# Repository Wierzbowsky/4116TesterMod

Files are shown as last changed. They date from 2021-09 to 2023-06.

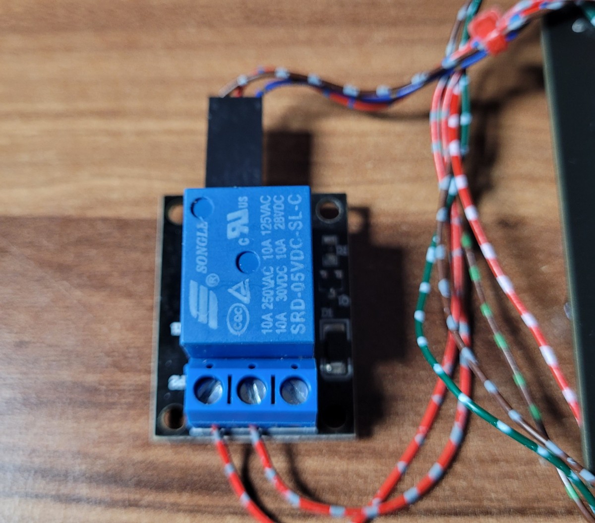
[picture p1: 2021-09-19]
Pics/relay.jpg

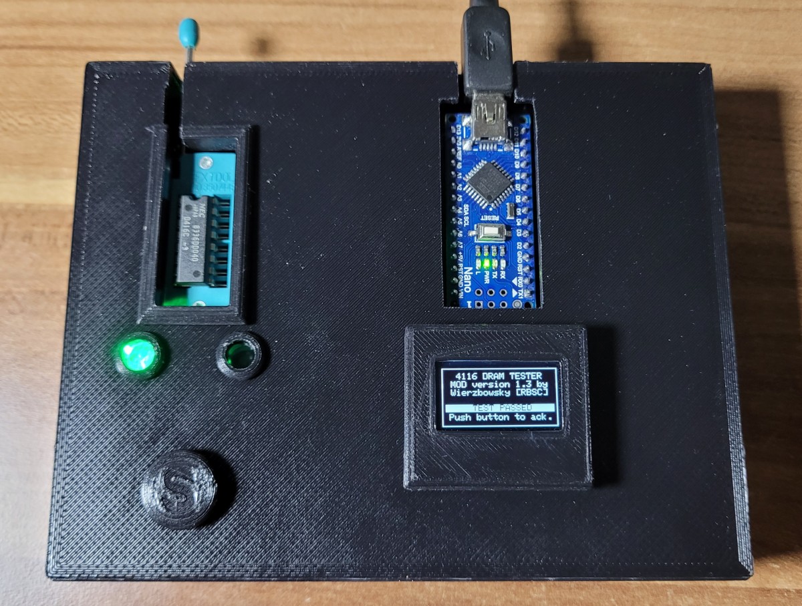
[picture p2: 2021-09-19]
Pics/case2.jpg

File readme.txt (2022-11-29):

--------------------------------------------------------------------------------
4116 DRAM Tester v3.0
Firmware fix by Uffe Lund-Hansen, 2017-2020
Mods by Alex Wierzbowsky [RBSC], 2021-2022
--------------------------------------------------------------------------------

WARNING!
If you applied the power mod to the tester, do not use the 9v power socket!
Power the tester only with the USB cable connected to Ardino Nano's Mini/MicroUSB connector.

IMPORTANT!
It's recommended to use a computer's USB3 port to power the tester because USB3 provides enough current
for the device to work properly. You can also power the tester with any 5v 500mA rated power supply that
is connected to the Mini/MicroUSB connector (for example phone charger).

ABOUT
-----

The original project was created in November 2017. The code was officially released in March 2020. Most of the
code and design was coming from http://forum.defence-force.org/viewtopic.php?p=15035&sid=17bf402b9c2fd97c8779668b8dde2044
by forum's member "iss" and was modified to work with 4116 DRAM by Uffe Lund-Hansen, Frostbox Labs.

The board for the project was modded from the original design by Muttley Black. However, the board was not safe
to use because there was always power on the chip's socket. Inserting a DRAM chip with the enabled +12v, -5v
and +5v is rather dangerous and in case of a wrongly inserted chip, damage may occur to the chip and the tester
itself.

Also, the firmware was designed to run only once, then the Arduino had to be reset by the Start button or by
the on-board reset button. The original firmware also had some minimal serial interface reporting capabilities.

Taking into account the above mentioned drawbacks, it was decided to mod the tester's hardware and firmware
in order to make it safer and more usable. Three mods were created for this project:

1. Button mod: v1.1

   This is simple. The button needs to be disconnected from RST pin and connected to A6 pin of Arduino Nano.
   The firmware was modified to use the button not to reset the Arduino, but to start a test and then confirm
   the test result. Some led blinking was added to indicate in which mode the tester is at any moment. If
   both LEDs are blinking, the tester awaits a chip to be inserted and the button to be pressed for the test
   to start. If green or red LED is lit, this indicates a successful or a failed test. The serial interface
   messages were improved to report the test results, tester's version and when the tester needs a user's
   interaction.

2. Power mod: v1.2

   This mod requires the Button mod to be installed!

   The power mod was created to disable the power on the chip's socket and to only enable it during testing. This
   makes it safe to insert a DRAM chip and also quickly cuts off the power in case a chip is shorted or inserted
   in a wrong way. The simple relay module for Arduino was used to enable or disable +5v power to the socket and
   +12v and -5v converters. The 5v track needs to be cut in 2 places, one wire needs to be added from the cut
   off +5v track to pin 9 of the socket. And the relay needs to be connected to both sides of the cut track.

   The relay is controlled by the signal that has to be connected to D12 pin of Arduino Nano. The relay's control
   circuit needs its own power and ground wires, the +5v has to be taken from the always powered part of the
   circuit. See the pictures in the "Pic" folder for the necessary modifications.

3. OLED screen mod: v1.3

   This mod requires at least the Button mod to be installed!

   To make the tester more informative an OLED screen was added into the project. As Arduino Nano has SCL and SDA
   signals available on A4 and A5 pins and those pins were used by the original tester's designer for the chip's
   socket, before the screen's installation those connections need to be rewired. A4 needs to be rewired to D10
   and A5 needs to be rewired to D11 pins of Arduino Nano. The tracks from A4 and A5 leading to resistors need to
   be cut. Then the screen's SCL and SDA pins need to be connected to Arduino's SCL and SDA pins. See Arduino's
   pinout for reference. Don't forget to connect VCC pin of the screen to Arduino's 3.3v pin and the GND pin of
   the screen to one of GND pins of the Arduino or to any other solder point on the ground plane. See the
   pictures in the "Pic" folder for the necessary modifications.

   The mod is designed to work with the 128x64 SSD1306 OLED screen. Before compiling the firmware please add the
   required Adafruit libaray for SSD1306 screen into your Arduino IDE environment.

   Because of the large size of the firmware after adding the support for the OLED screen, the serial interface
   messages were commented out to save space in the firmware.

When applying the mods, don't forget to upload the corresponding firmware version into Arduino Nano. See the
"Firmware" folder for the available firmwares. Some Arduinos may require selecting "older Bootloader" option
in the IDE to be flashed.

And finally, 3D models of the case were created for the project. There's a wide case that can hold the relay
board and a narrow case for the tester's board by Muttley Black. Both cases can be used for installing the
OLED screen's frame. If you only want the button and screen mods, you can use the narrow case. Please keep
in mind that if you are installing the boards into these cases, you will need to make the socket's lever a bit
longer by attaching a thin plastic or metal tube to it. The current case's design is not ideal for inserting
DRAM chips, so it's recommended to use tweezers if you have trouble inserting or removing a chip.

The Gerber files for that board are located in the "Gerber" folder. The 3D models of the case as well as frames
for the screen are also available in the "Case" folder. The "Original" folder contains the narrow case, the
"Modded" folder contains the wide case.

The videos of the tester's mods can be found on Wierzbowsky's YouTube channel:
https://www.youtube.com/channel/UCefKNRX9MJG4uGqiBBtaJVA/videos

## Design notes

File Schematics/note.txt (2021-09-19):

This schematics doesn't include the modifications added by Muttley Black. The modifications included adding
twelve 150 Ohm current limiting resistors between the Arduino Nano and the chip's socket.

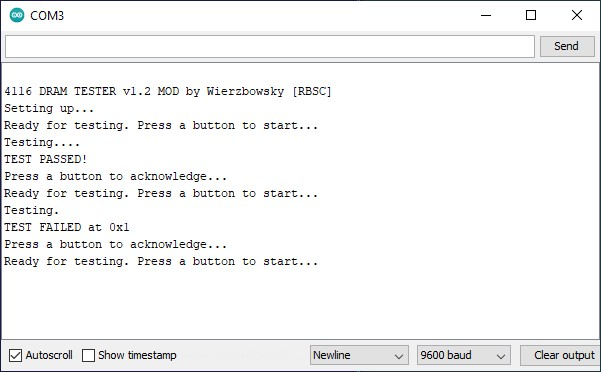
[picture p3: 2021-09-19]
Pics/serial_io.png

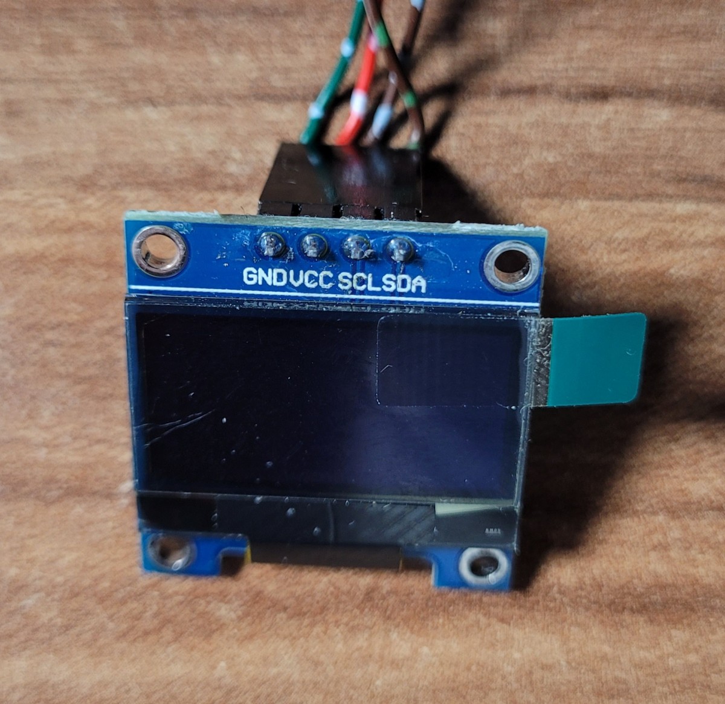
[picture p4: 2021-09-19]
Pics/screen.jpg

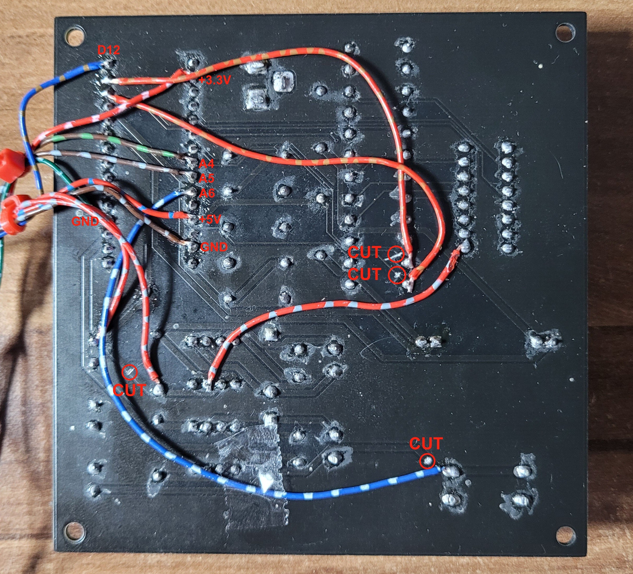
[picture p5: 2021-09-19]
Pics/board_back.jpg

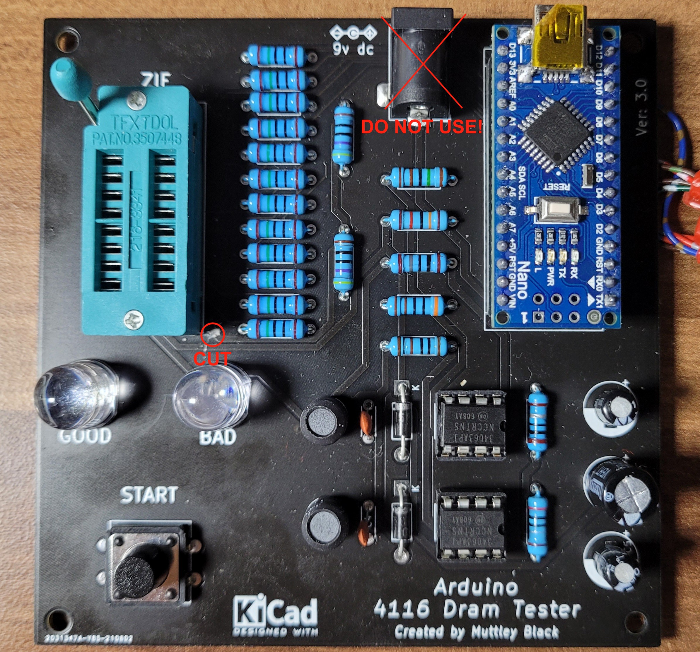
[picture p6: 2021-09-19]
Pics/board_front.jpg

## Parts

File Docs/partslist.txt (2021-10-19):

1  A1 - Arduino Nano v3.x : Module:Arduino Nano 
2  C1 - 100uF 16V : Capacitor THT:CP Radial D8.0mm P3.80mm 
3  C2 - 470pF : Capacitor THT:C_Disc_D4.3mm W1.9mm P5.00mm 
4  C3 - 470uF 16V : Capacitor THT:CP Radial D8.0mm P3.80mm 
5  C4 - 330pF : Capacitor THT:C_Disc_D4.3mm W1.9mm P5.00mm 
6  C5 - 100uF 16V : Capacitor THT:CP Radial D8.0mm P3.80mm 
7  D1 - Green : LED THT:LED D5.0mm 
8  D2 - Red : LED THT:LED D5.0mm 
9  D3 - 1N5819 : Diode_THT:D_DO-41_SOD81_P10.16mm Horizontal 
10 D4 - 1N5819 : Diode_THT:D_DO-41_SOD81_P10.16mm Horizontal 
11 J1 - ZIF socket 16 pin : Socket:DIP_Socket-16 W4.3 W5.08 W7.62 W10.16 W10.9_3M 216-3340-00-0602J 
12 J2 - 9v dc : Connector_BarrelJack:BarrelJack Horizontal 
13 L1 - 2mH : Inductor THT:L Radial D6.0mm P4.00mm 
14 L2 - 2mH : Inductor THT:L Radial D6.0mm P4.00mm 
15 R1 - 470 Ohm : Resistor THT:R Axial_DINO207_L6.3mm D2.5mm P10.16mm Horizontal 
16 R2 - 470 Ohm : Resistor THT:R Axial_DINO207_L6.3mm D2.5mm P10.16mm Horizontal 
17 R3 - 1 Ohm : Resistor THT:R Axial_DINO207_L6.3mm D2.5mm P10.16mm Horizontal 
18 R4 - 1.5 kOhm : Resistor THT:R Axial_DINO207_L6.3mm D2.5mm P10.16mm Horizontal 
19 R5 - 13 kOhm : Resistor THT:R Axial_DINO207_L6.3mm D2.5mm P10.16mm Horizontal 
20 R6 - 180 Ohm : Resistor THT:R Axial_DINO207_L6.3mm D2.5mm P10.16mm Horizontal 
21 R7 - 2 Ohm  : Resistor THT:R Axial_DINO207_L6.3mm D2.5mm P10.16mm Horizontal 
22 R8 - 3 kOhm : Resistor THT:R Axial_DINO207_L6.3mm D2.5mm P10.16mm Horizontal 
23 R9 - l kOhm : Resistor THT:R Axial_DINO207_L6.3mm D2.5mm P10.16mm Horizontal 
24 R10 - 150 Ohm : Resistor THT:R Axial_DINO207_L6.3mm D2.5mm P10.16mm Horizontal 
25 R11 - 150 Ohm : Resistor THT:R Axial_DINO207_L6.3mm D2.5mm P10.16mm Horizontal 
26 R12 - 150 Ohm : Resistor THT:R Axial_DINO207_L6.3mm D2.5mm P10.16mm Horizontal 
27 R13 - 150 Ohm : Resistor THT:R Axial_DINO207_L6.3mm D2.5mm P10.16mm Horizontal 
28 R14 - 150 Ohm : Resistor THT:R Axial_DINO207_L6.3mm D2.5mm P10.16mm Horizontal 
29 R15 - 150 Ohm : Resistor THT:R Axial_DINO207_L6.3mm D2.5mm P10.16mm Horizontal 
30 R16 - 150 Ohm : Resistor THT:R Axial_DINO207_L6.3mm D2.5mm P10.16mm Horizontal 
31 R17 - 150 Ohm : Resistor THT:R Axial_DINO207_L6.3mm D2.5mm P10.16mm Horizontal 
32 R18 - 150 Ohm : Resistor THT:R Axial_DINO207_L6.3mm D2.5mm P10.16mm Horizontal 
33 R19 - 150 Ohm : Resistor THT:R Axial_DINO207_L6.3mm D2.5mm P10.16mm Horizontal 
34 R20 - 150 Ohm : Resistor THT:R Axial_DINO207_L6.3mm D2.5mm P10.16mm Horizontal 
35 R21 - 150 Ohm : Resistor THT:R Axial_DINO207_L6.3mm D2.5mm P10.16mm Horizontal 
36 SW1 - SW_Push : Button_Switch THT:SW_PUSH-12mm 
37 U1 - MC34063AP : Package_DIP:DIP-8 W7.62mm 
38 U2 - MC34063AP : Package_DIP:DIP-8 W7.62mm

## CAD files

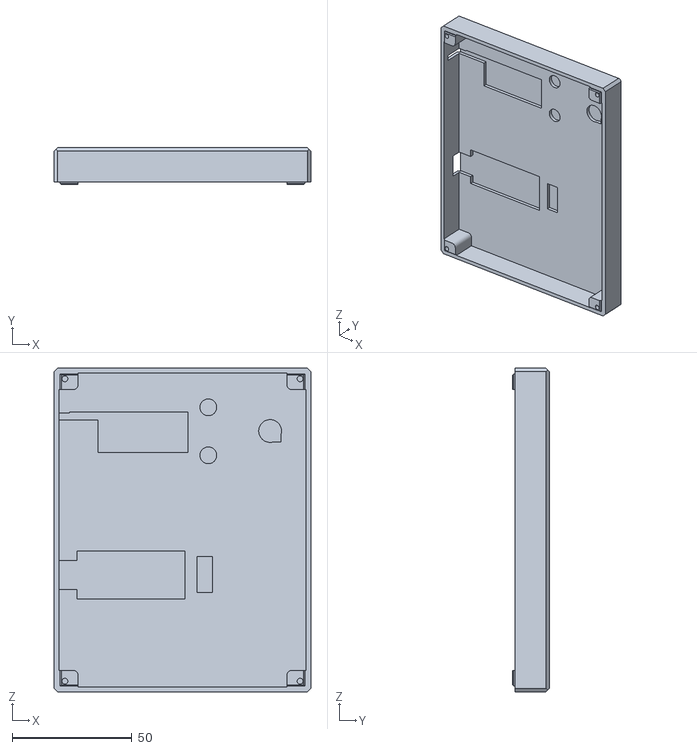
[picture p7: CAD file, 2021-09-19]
Case/Modded/Top_NoHoles.stl
107.0 x 15.5 x 135.0

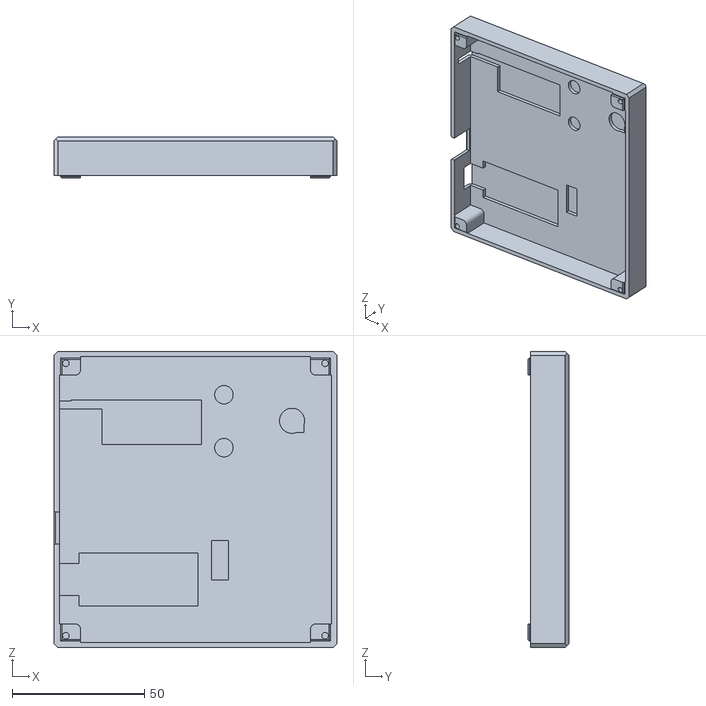
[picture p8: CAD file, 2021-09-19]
Case/Original/Top_NoHoles.stl
107.0 x 15.5 x 112.0

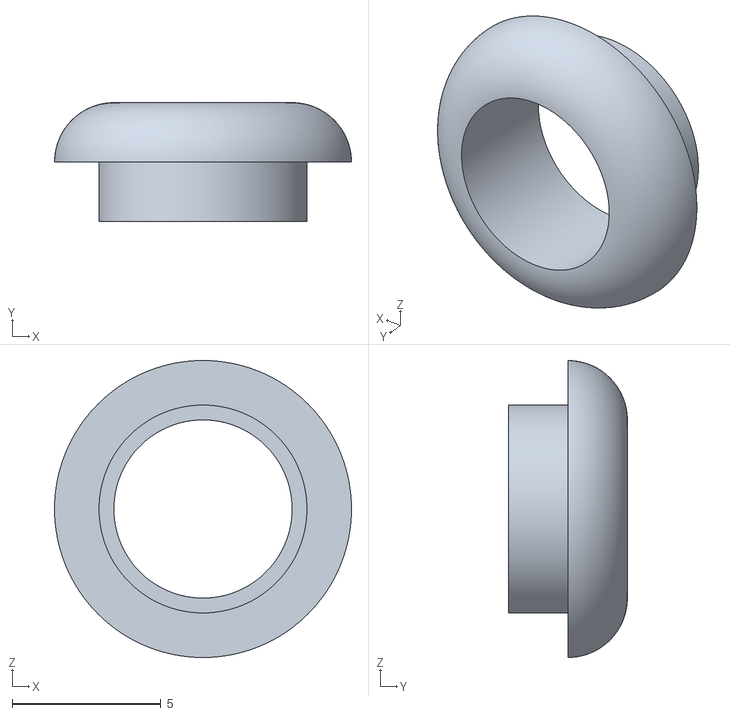
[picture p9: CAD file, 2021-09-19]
Case/Modded/LEDCap.stl
10.0 x 4.00 x 10.0

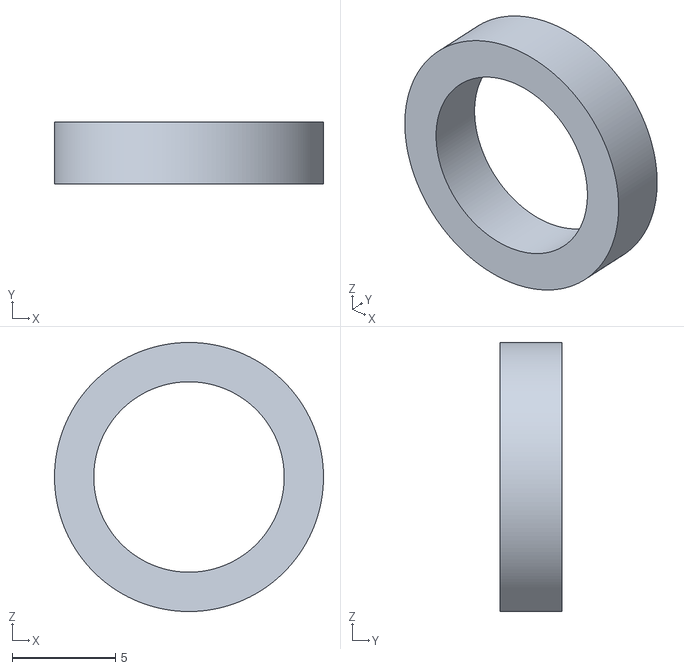
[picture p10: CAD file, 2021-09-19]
Case/Original/ButtoncapLock.stl
13.0 x 3.00 x 13.0

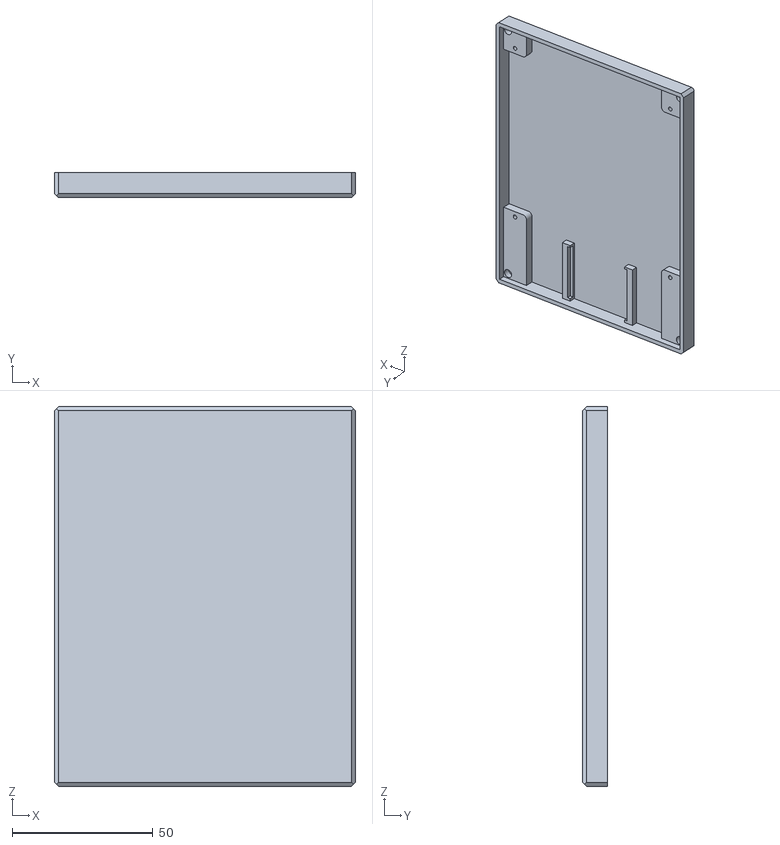
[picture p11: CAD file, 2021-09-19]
Case/Modded/Bottom_NoHoles.stl
107.0 x 9.00 x 135.0

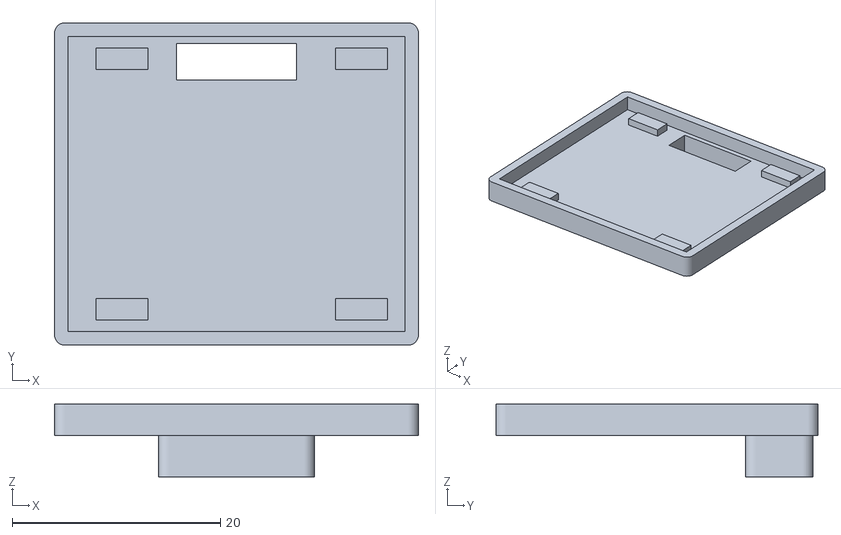
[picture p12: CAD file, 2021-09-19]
Case/Original/CoverBack.stl
35.0 x 31.0 x 7.00

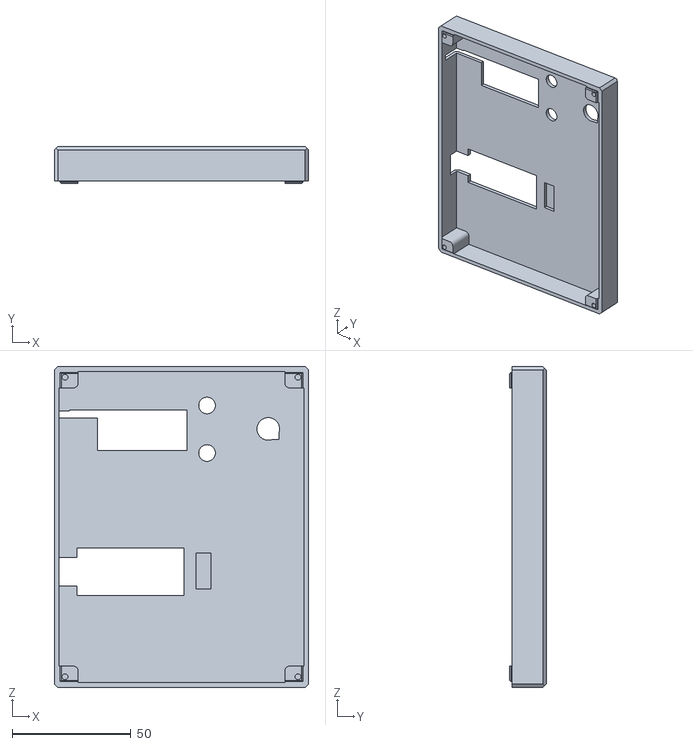
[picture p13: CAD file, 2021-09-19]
Case/Modded/Top_NoScreen.stl
107.0 x 15.5 x 135.0

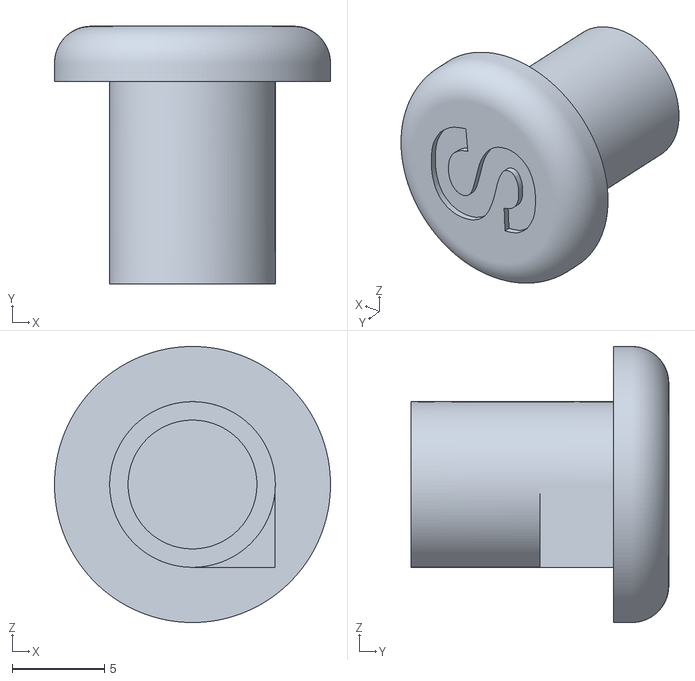
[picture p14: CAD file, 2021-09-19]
Case/Original/Buttoncap.stl
15.0 x 14.0 x 15.0

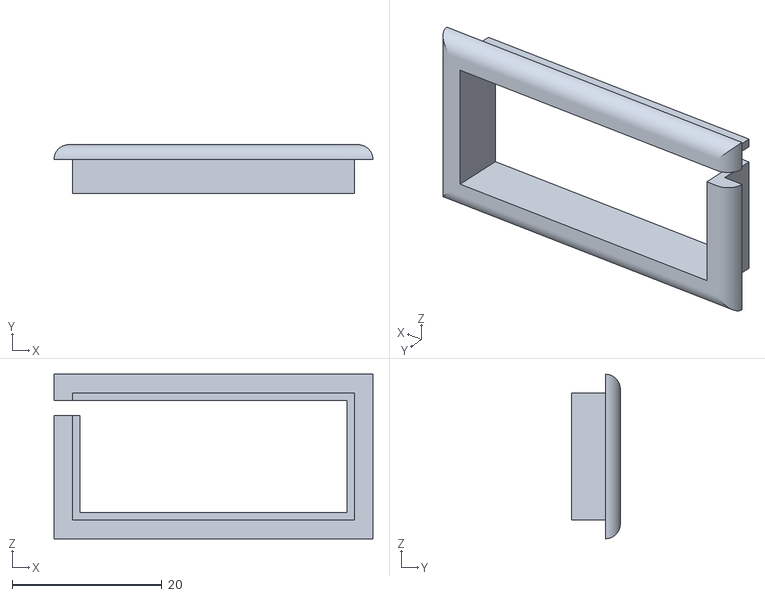
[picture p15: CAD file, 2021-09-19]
Case/Modded/SocketFrame.stl
42.6 x 6.50 x 21.9

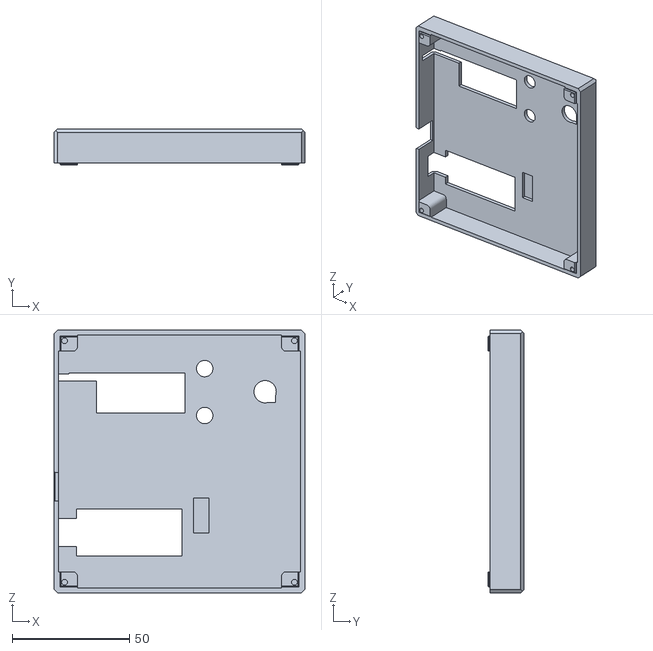
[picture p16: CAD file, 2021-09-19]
Case/Original/Top_NoScreen.stl
107.0 x 15.5 x 112.0

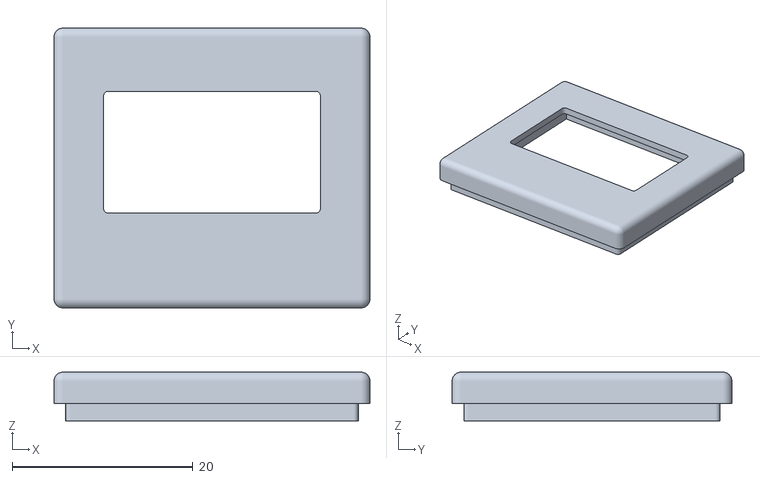
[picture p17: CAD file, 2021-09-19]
Case/Modded/CoverFront.stl
35.0 x 31.0 x 5.40

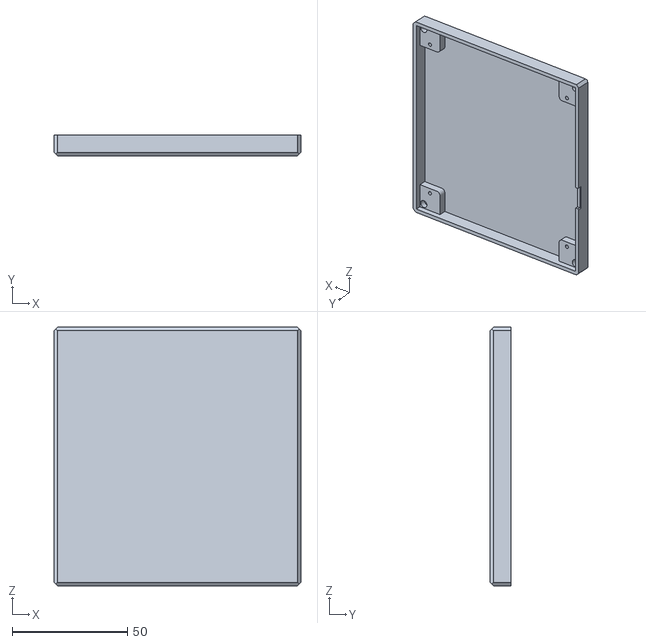
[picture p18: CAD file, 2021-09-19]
Case/Original/Bottom_NoHoles.stl
107.0 x 9.00 x 112.0

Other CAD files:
Case/Modded/Top.stl
Case/Original/Bottom.stl
Case/Modded/Bottom.stl
Case/Original/LEDCap.stl
Case/Original/Top.stl

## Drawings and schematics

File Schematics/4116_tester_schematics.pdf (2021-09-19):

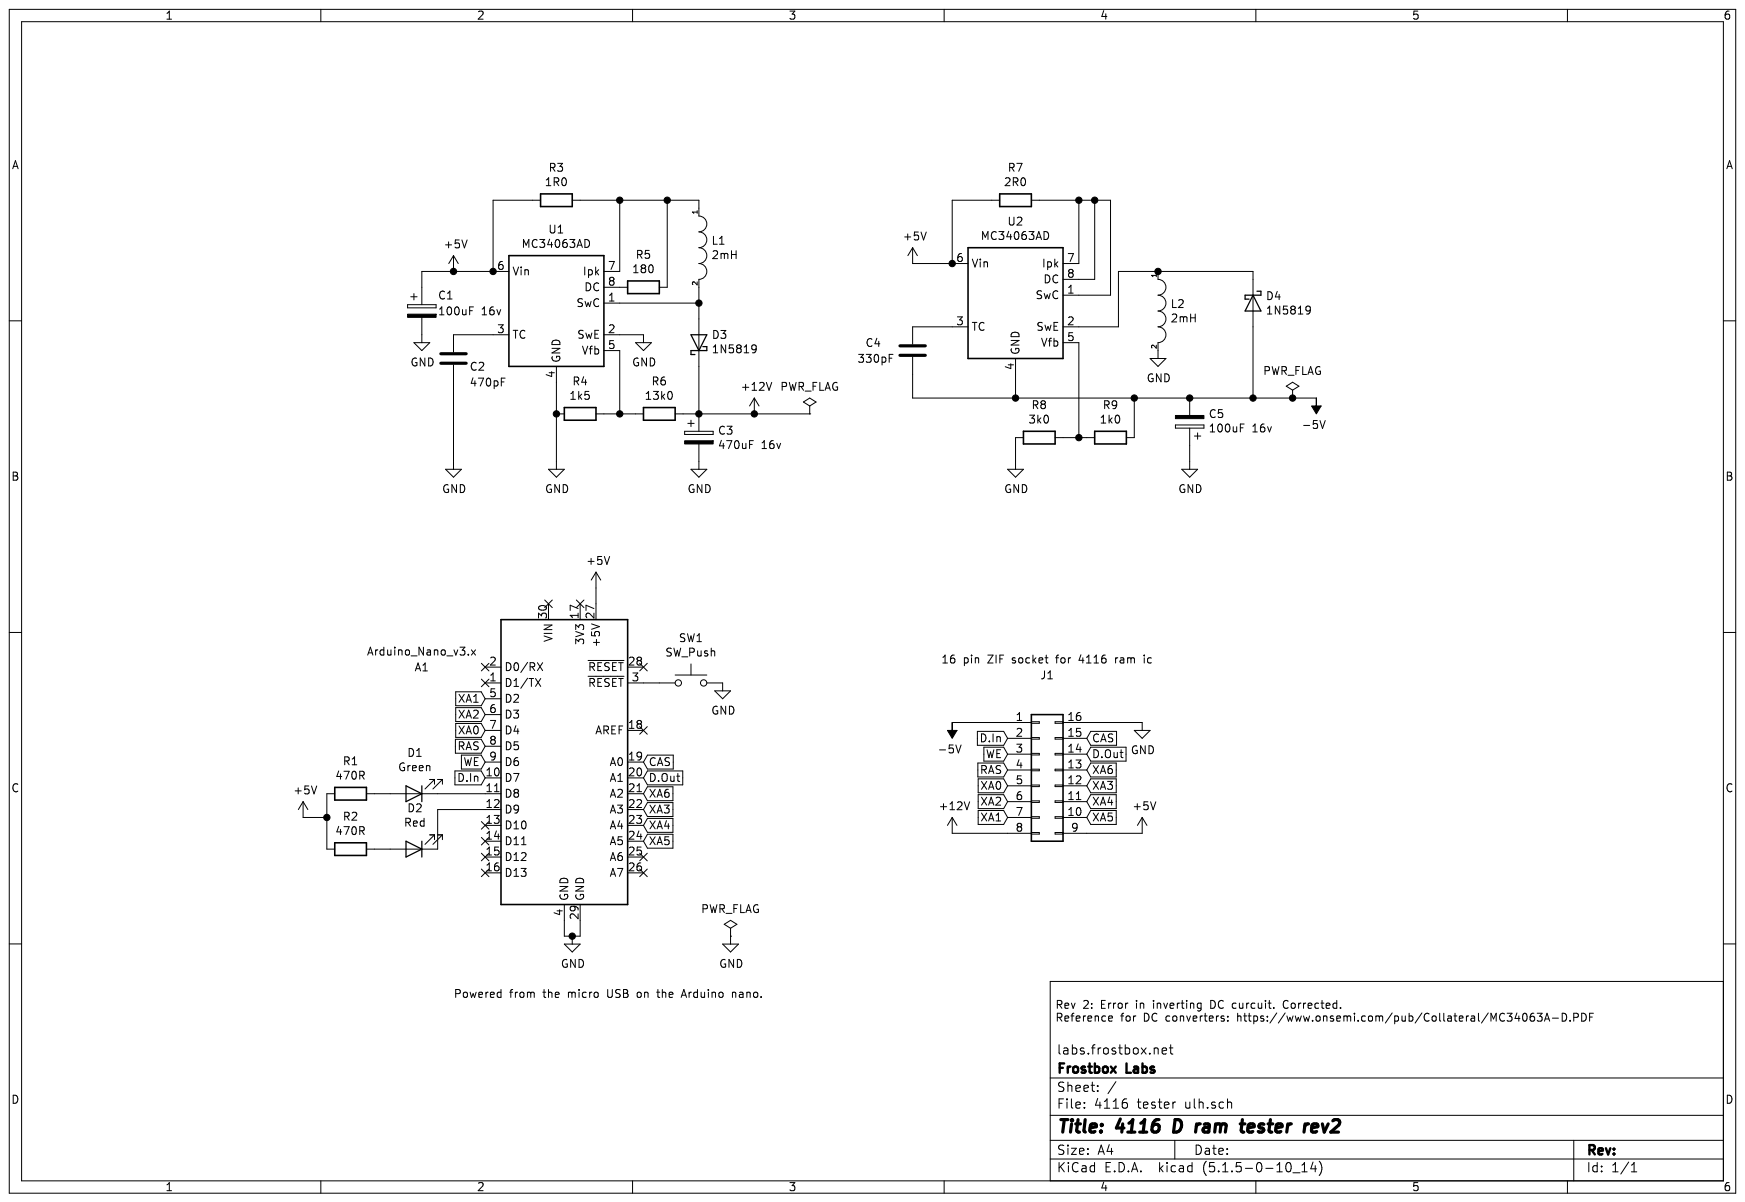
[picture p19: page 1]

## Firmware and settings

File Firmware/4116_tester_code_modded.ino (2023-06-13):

//
// 4116 DRAM Tester Firmware. v3.1
//
// Created in November 2017. Code commented and posted in March 2020. 
// Most of the code and design is from http://forum.defence-force.org/viewtopic.php?p=15035&sid=17bf402b9c2fd97c8779668b8dde2044
// by forum member "iss" and modified to work with 4116 D ram by me Uffe Lund-Hansen, Frostbox Labs. 
//
// Mod: The firmware was modified by Wierzbowsky [RBSC] in September 2021. Mod v1.3
// Board: v3.0 with the push button disconnected from RST and connected to A6 of Arduino Nano
//
// The additional relay module can be connected to the board to enable the power on the
// chip's socket only during DRAM's testing, the control signal is wired to D12 of Arduino Nano
//
// An OLED screen can be connected to the A4 and A5 pins of Arduino Nano (SDA and SCL)
// The previous connections from A4 and A5 to resistors should be rewired to D10 and D11 respectively!
// This mod and firmware is designed for 128x64 SSD1306 OLED screen, the serial output is disabled when screen is used
//

#include <SoftwareSerial.h>
#include <Wire.h>
#include <Adafruit_GFX.h>
#include <Adafruit_SSD1306.h>

#define OLED_RESET 4
#define I2C_ADDRESS 0x3C
#define SCREEN_WIDTH 128
#define SCREEN_HEIGHT 64

//Adafruit_SSD1306 display(OLED_RESET);
Adafruit_SSD1306 display(SCREEN_WIDTH, SCREEN_HEIGHT, &Wire, OLED_RESET);

#define DI          7     //  Arduino D7  > 4116 pin 2
#define DO          15    //  Arduino A1  > 4116 pin 14
#define CAS         14    //  Arduino A0  > 4116 pin 15
#define RAS         5     //  Arduino D5  > 4116 pin 4
#define WE          6     //  Arduino D6  > 4116 pin 3

#define XA0         4     //  Arduino D4  > 4116 pin 5
#define XA1         2     //  Arduino D2  > 4116 pin 7
#define XA2         3     //  Arduino D3  > 4116 pin 6
#define XA3         17    //  Arduino A3  > 4116 pin 12
//#define XA4         18    //  Arduino A4 > 4116 pin 11
//#define XA5         19    //  Arduino A5 > 4116 pin 10
#define XA4         10    //  Arduino D10 > 4116 pin 11
#define XA5         11    //  Arduino D11 > 4116 pin 10
#define XA6         16    //  Arduino A2  > 4116 pin 13

#define SDA         18    //  Arduino A4 > screen SDA
#define SCL         19    //  Arduino A5 > screen SCL

#define R_LED       9     //  Arduino D9 > Cathode on red LED. Anode connected through 470ohm resisor to +5VDC 
#define G_LED       8     //  Arduino D8 > Cathode on green LED. Anode connected through 470ohm resisor to +5VDC

#define BUTN        20    //  Arduino A6  > Start button
#define PWR         12    //  Arduino D12 > Socket power on/off via relay
#define NLED        13    //  Arduino D13 > NanoLED

#define BUS_SIZE    7

volatile int bus_size;

int buttondown;

const unsigned int a_bus[BUS_SIZE] = {
  XA0, XA1, XA2, XA3, XA4, XA5, XA6
};

void setBus(unsigned int a) {
  int i;
  for (i = 0; i < BUS_SIZE; i++) {
    digitalWrite(a_bus[i], a & 1);
    a /= 2;
  }
}

void writeAddress(unsigned int r, unsigned int c, int v) {
  /* row */
  setBus(r);
  digitalWrite(RAS, LOW);

  /* rw */
  digitalWrite(WE, LOW);

  /* val */
  digitalWrite(DI, (v & 1) ? HIGH : LOW);

  /* col */
  setBus(c);
  digitalWrite(CAS, LOW);

  digitalWrite(WE, HIGH);
  digitalWrite(CAS, HIGH);
  digitalWrite(RAS, HIGH);
}

int readAddress(unsigned int r, unsigned int c) {
  int ret = 0;

  /* row */
  setBus(r);
  digitalWrite(RAS, LOW);

  /* col */
  setBus(c);
  digitalWrite(CAS, LOW);

  /* get current value */
  ret = digitalRead(DO);

  digitalWrite(CAS, HIGH);
  digitalWrite(RAS, HIGH);

  return ret;
}

void TestFailed(int r, int c)
{
  unsigned long a = ((unsigned long)c << bus_size) + r;
  digitalWrite(R_LED, LOW);
  digitalWrite(G_LED, HIGH);
  digitalWrite(NLED, 1); // Nano led on
  digitalWrite(PWR, LOW); // power off

  interrupts();
//  Serial.println();
//  Serial.print("TEST FAILED at 0x");
//  Serial.println(a, HEX);
//  Serial.println("Press a button to acknowledge...");
//  Serial.flush();

  ClearSpace();
  display.setTextColor(SSD1306_BLACK, SSD1306_WHITE);
  display.setCursor(4,40);
  display.println("    TEST FAILED!!   ");
  display.setTextColor(SSD1306_WHITE);
  display.setCursor(2,50);
  display.println(" Push button to ack.");
  display.display();
}

void TestOK(void)
{
  digitalWrite(R_LED, HIGH);
  digitalWrite(G_LED, LOW);
  digitalWrite(NLED, 0); // Nano led off
  digitalWrite(PWR, LOW); // power off
  
  interrupts();  
//  Serial.println();
//  Serial.println("TEST PASSED!");
//  Serial.println("Press a button to acknowledge...");
//  Serial.flush();

  ClearSpace();
  display.setTextColor(SSD1306_BLACK, SSD1306_WHITE);
  display.setCursor(4,40);
  display.println("     TEST PASSED    ");
  display.setTextColor(SSD1306_WHITE);
  display.setCursor(2,50);
  display.println(" Push button to ack.");
  display.display();
}

void BlinkLEDs(void)
{
  digitalWrite(G_LED, LOW);
  digitalWrite(R_LED, LOW);
  digitalWrite(NLED, 1); // Nano led on
  delay(1000);
  digitalWrite(R_LED, HIGH);
  digitalWrite(G_LED, HIGH);
  digitalWrite(NLED, 0); // Nano led off
}

void SetGreen(int v)
{
  digitalWrite(G_LED, v);
}

boolean Test2(int v)
{
  int r, c, g = 0;
  v &= 1;
  for (c = 0; c < (1 << bus_size); c++) {
    SetGreen(g ? HIGH : LOW);
    for (r = 0; r < (1 << bus_size); r++) {
      writeAddress(r, c, v);
      if (v != readAddress(r, c))
      {
        TestFailed(r, c);
        return false;
      }
    }
    g ^= 1;
  }
  BlinkLEDs();
  return true;
}

boolean Test1(int v)
{
  int r, c, g = 0;
  v &= 1;
  for (c = 0; c < (1 << bus_size); c++) {
    SetGreen(g ? HIGH : LOW);
    for (r = 0; r < (1 << bus_size); r++) {
      writeAddress(r, c, v);
      if (v != readAddress(r, c))
      {
        TestFailed(r, c);
        return false;
      }
      v ^= 1;
    }
    g ^= 1;
  }
  BlinkLEDs();
  return true;
}

int ButtonCheck(void)
{
  const int divider = 10;
  int cnt;

//  if (digitalRead(BUTN) == LOW)
//  {
//    while(digitalRead(BUTN)== LOW) delay (50);
//    return 0;
//  }
//  else return 1;

    for (cnt = 0; cnt < divider; cnt++)
    {
      delay(100);
      buttondown = analogRead(BUTN);
      if (!buttondown) break;
    }
    while(analogRead(BUTN)== 0) delay (50);
    if (!buttondown) return 0;
    else return 1;

//  if (analogRead(BUTN) == 0)
//  {
//    while(analogRead(BUTN)== 0) delay (50);
//    return 0;
//  }
//  else return 1;
}

void ClearSpace()
{
  display.fillRect(1, 32, 126, 31, SSD1306_BLACK);
  display.display();
}

void setup() {
  int i;

  Serial.begin(9600);
  while (!Serial)
    ; /* wait */

  digitalWrite(NLED, 1); // Nano led on

  display.begin(SSD1306_SWITCHCAPVCC, I2C_ADDRESS);
  display.clearDisplay();
  display.setTextSize(1);
  display.cp437(true);
  display.setTextColor(SSD1306_WHITE);

//  Serial.println();
//  Serial.println("4116 DRAM TESTER v1.3 MOD by Wierzbowsky [RBSC]");
//  Serial.println("Setting up...");

  display.drawRect(0, 0, SCREEN_WIDTH, SCREEN_HEIGHT, SSD1306_WHITE);
  display.setCursor(4,5);
  display.println("  4116 DRAM TESTER");
  display.setCursor(4,14);
  display.println(" MOD version 1.3 by");
  display.setCursor(4,23);
  display.println(" Wierzbowsky [RBSC]");
  display.setCursor(4,40);
  display.println("    Setting up...");
  display.display();
  delay(1000);

  for (i = 0; i < BUS_SIZE; i++)
    pinMode(a_bus[i], OUTPUT);
  
  pinMode(CAS, OUTPUT);
  pinMode(RAS, OUTPUT);
  pinMode(WE, OUTPUT);
  pinMode(DI, OUTPUT);

  pinMode(R_LED, OUTPUT);
  pinMode(G_LED, OUTPUT);

  pinMode(DO, INPUT);
  
 // pinMode(BUTN, INPUT_PULLUP);  // for Start button (connected to A6)
  
  pinMode(PWR, OUTPUT);  // for power on/off
  
  digitalWrite(PWR, LOW);
  
  digitalWrite(WE, HIGH);
  digitalWrite(RAS, HIGH);
  digitalWrite(CAS, HIGH);

  digitalWrite(R_LED, LOW);
  digitalWrite(G_LED, LOW);

  bus_size = BUS_SIZE;

  noInterrupts();
  for (i = 0; i < (1 << BUS_SIZE); i++) {
    digitalWrite(RAS, LOW);
    digitalWrite(RAS, HIGH);
  }

  digitalWrite(NLED, 0); // Nano led off
  interrupts();
}

void loop()
{
  digitalWrite(PWR, LOW); // power off

//  Serial.println("Ready for testing. Press a button to start...");
//  Serial.flush();

  while(1)  // main waiting loop
  {
    ClearSpace();
    display.setTextColor(SSD1306_BLACK, SSD1306_WHITE); // inverse
    display.setCursor(4,40);
    display.println("   PUSH BUTTON TO   ");
    display.setCursor(4,48);
    display.println("  TO START TESTING  ");
    display.setTextColor(SSD1306_WHITE);
    display.display();

    digitalWrite(R_LED, LOW);
    digitalWrite(G_LED, LOW);
    digitalWrite(NLED, 1); // Nano led on
    
    if (!ButtonCheck()) break;

    ClearSpace();
    display.setCursor(4,40);
    display.println("   PUSH BUTTON TO   ");
    display.setCursor(4,48);
    display.println("  TO START TESTING  ");
    display.display();

    digitalWrite(R_LED, HIGH);
    digitalWrite(G_LED, HIGH);
    digitalWrite(NLED, 0); // Nano led off
    
   if (!ButtonCheck()) break;
  }

  // LEDS off
  interrupts();
  digitalWrite(G_LED, HIGH);
  digitalWrite(R_LED, HIGH);
  digitalWrite(NLED, 0); // Nano led off

  // Start test
  interrupts();
//  Serial.print("Testing");
//  Serial.print(".");
//  Serial.flush();

  ClearSpace();
  display.setTextColor(SSD1306_WHITE);
  display.setCursor(1,40);
  display.println("       TESTING      ");
  display.drawRect(20, 50, 90, 10, SSD1306_WHITE);
  display.display();

  digitalWrite(PWR, HIGH);  // power on
  delay(1000);

  noInterrupts();
  if (Test1(0) == false)
  {
    interrupts();
    delay(1000);
    while(ButtonCheck());
    return;
  }
  else
  {  
    interrupts();
//    Serial.print(".");
//    Serial.flush();
    display.fillRect(20, 50, 22, 10, SSD1306_WHITE);
    display.display();
    noInterrupts();
    if (Test1(1) == false)
    {
      interrupts();
      delay(1000);
      while(ButtonCheck());
      return;
    }
    else
    {
      interrupts();
//      Serial.print(".");
//      Serial.flush();
      display.fillRect(20, 50, 44, 10, SSD1306_WHITE);
      display.display();
      noInterrupts();
      if (Test2(0) == false)
      {
        interrupts();
        delay(1000);
        while(ButtonCheck());
        return;
      }
      else
      {
        interrupts();
//        Serial.print(".");
//        Serial.flush();
        display.fillRect(20, 50, 66, 10, SSD1306_WHITE);
        display.display();
        noInterrupts();
        if (Test2(1) == false)
        {
          interrupts();
          delay(1000);
          while(ButtonCheck());
          return;
        }
        else
        {
          interrupts();
          display.fillRect(20, 50, 90, 10, SSD1306_WHITE);
          display.display();
          delay(1000);
          
          // Test passed
          TestOK();
          delay(1000);
          while(ButtonCheck());
        }
      }
    }
  }
}

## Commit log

2021-09-19 First release on 20.09.2021
    Initial release
    [4116 dram tester-B_Cu.gbr, 4116 dram tester-B_Mask.gbr, 4116 dram tester-B_Paste.gbr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]
2021-10-19 Updated 19.10.2021
    Updated readme, added BOM in text format after OCR
2022-11-29 Updated 29.11.2022
    Changed the pushbutton query routine to detect the push more reliably.
    Now test ack works correctly.
    [4116_tester_code_modded.ino]
2023-06-13 Updated 13.06.2023
    Fixed some bugs in failed test displaying routine
    [4116_tester_code_modded.ino]
